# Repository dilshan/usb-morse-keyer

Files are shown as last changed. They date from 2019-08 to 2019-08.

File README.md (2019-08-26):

# USB Morse Keyer
    

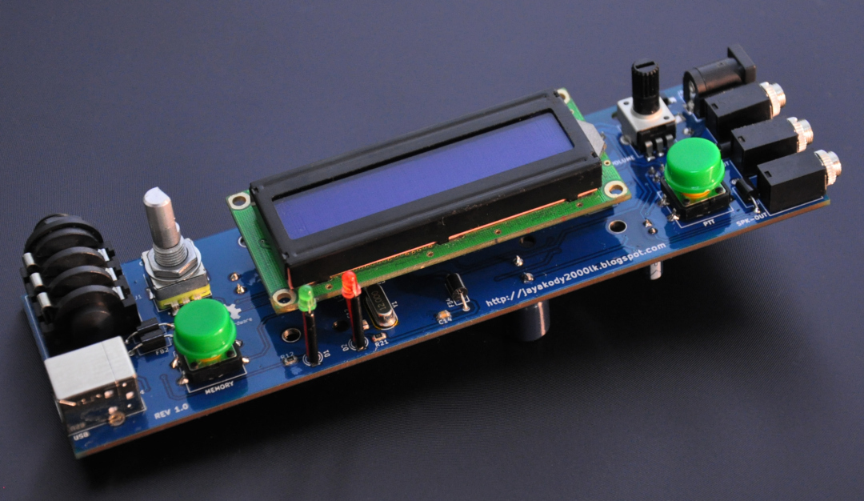
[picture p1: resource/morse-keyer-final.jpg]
Morse Keyer Final Prototype


USB Morse Keyer is microcontroller based keyer with following features:

- USB / straight key / iambic key inputs.
- Support for both *standalone* and *USB* operating modes.
- 64-character USB typeahead buffer and 6-character Morse key typeahead buffer.
- Support 5, 10, 15 WPM.
- 6-page message memory.
- 1W Audio output.
- Audio and PTT output interfaces.
- 32 character display

To reduce the dimension of the PCB this unit is designed with combining both through-hole and surface mount components. To facilitate future upgrades and modifications, the *PIC16F886* MCU sticks with the standard 28-pin DIP package.

The USB interface of this unit is designed to work with most of the operating systems. It emulates a virtual serial terminal to transfer keystrokes to the keyer. In most of the operating systems, this interface works without installing any additional device drivers. To submit keystrokes user can use any serial terminal software such as [PuTTY](https://www.putty.org), *Hyper Terminal*, [Minicom](https://salsa.debian.org/minicom-team/minicom), etc. 

This keyer is designed to work with 7V to 16V DC input voltage. The most recommended working voltage is 9V.

[All the details related to this project are available at project documentation.](https://github.com/dilshan/usb-morse-keyer/wiki)

## Licenses

This is a [certified](https://certification.oshwa.org/lk000004.html) open hardware project and all it's design files, firmware source codes, [documentation](https://github.com/dilshan/usb-morse-keyer/wiki), and other resource files are available at the project source repository. All the content of this project are distributed under the terms of the following license:

- Hardware License: [CC BY 4.0](https://creativecommons.org/licenses/by/4.0/)
- Software License: [MIT](https://github.com/dilshan/usb-morse-keyer/blob/master/LICENSE)
- Documentation License: [CC BY 4.0](https://creativecommons.org/licenses/by/4.0/)

OSHW-LK000004 (https://certification.oshwa.org/lk000004.html)

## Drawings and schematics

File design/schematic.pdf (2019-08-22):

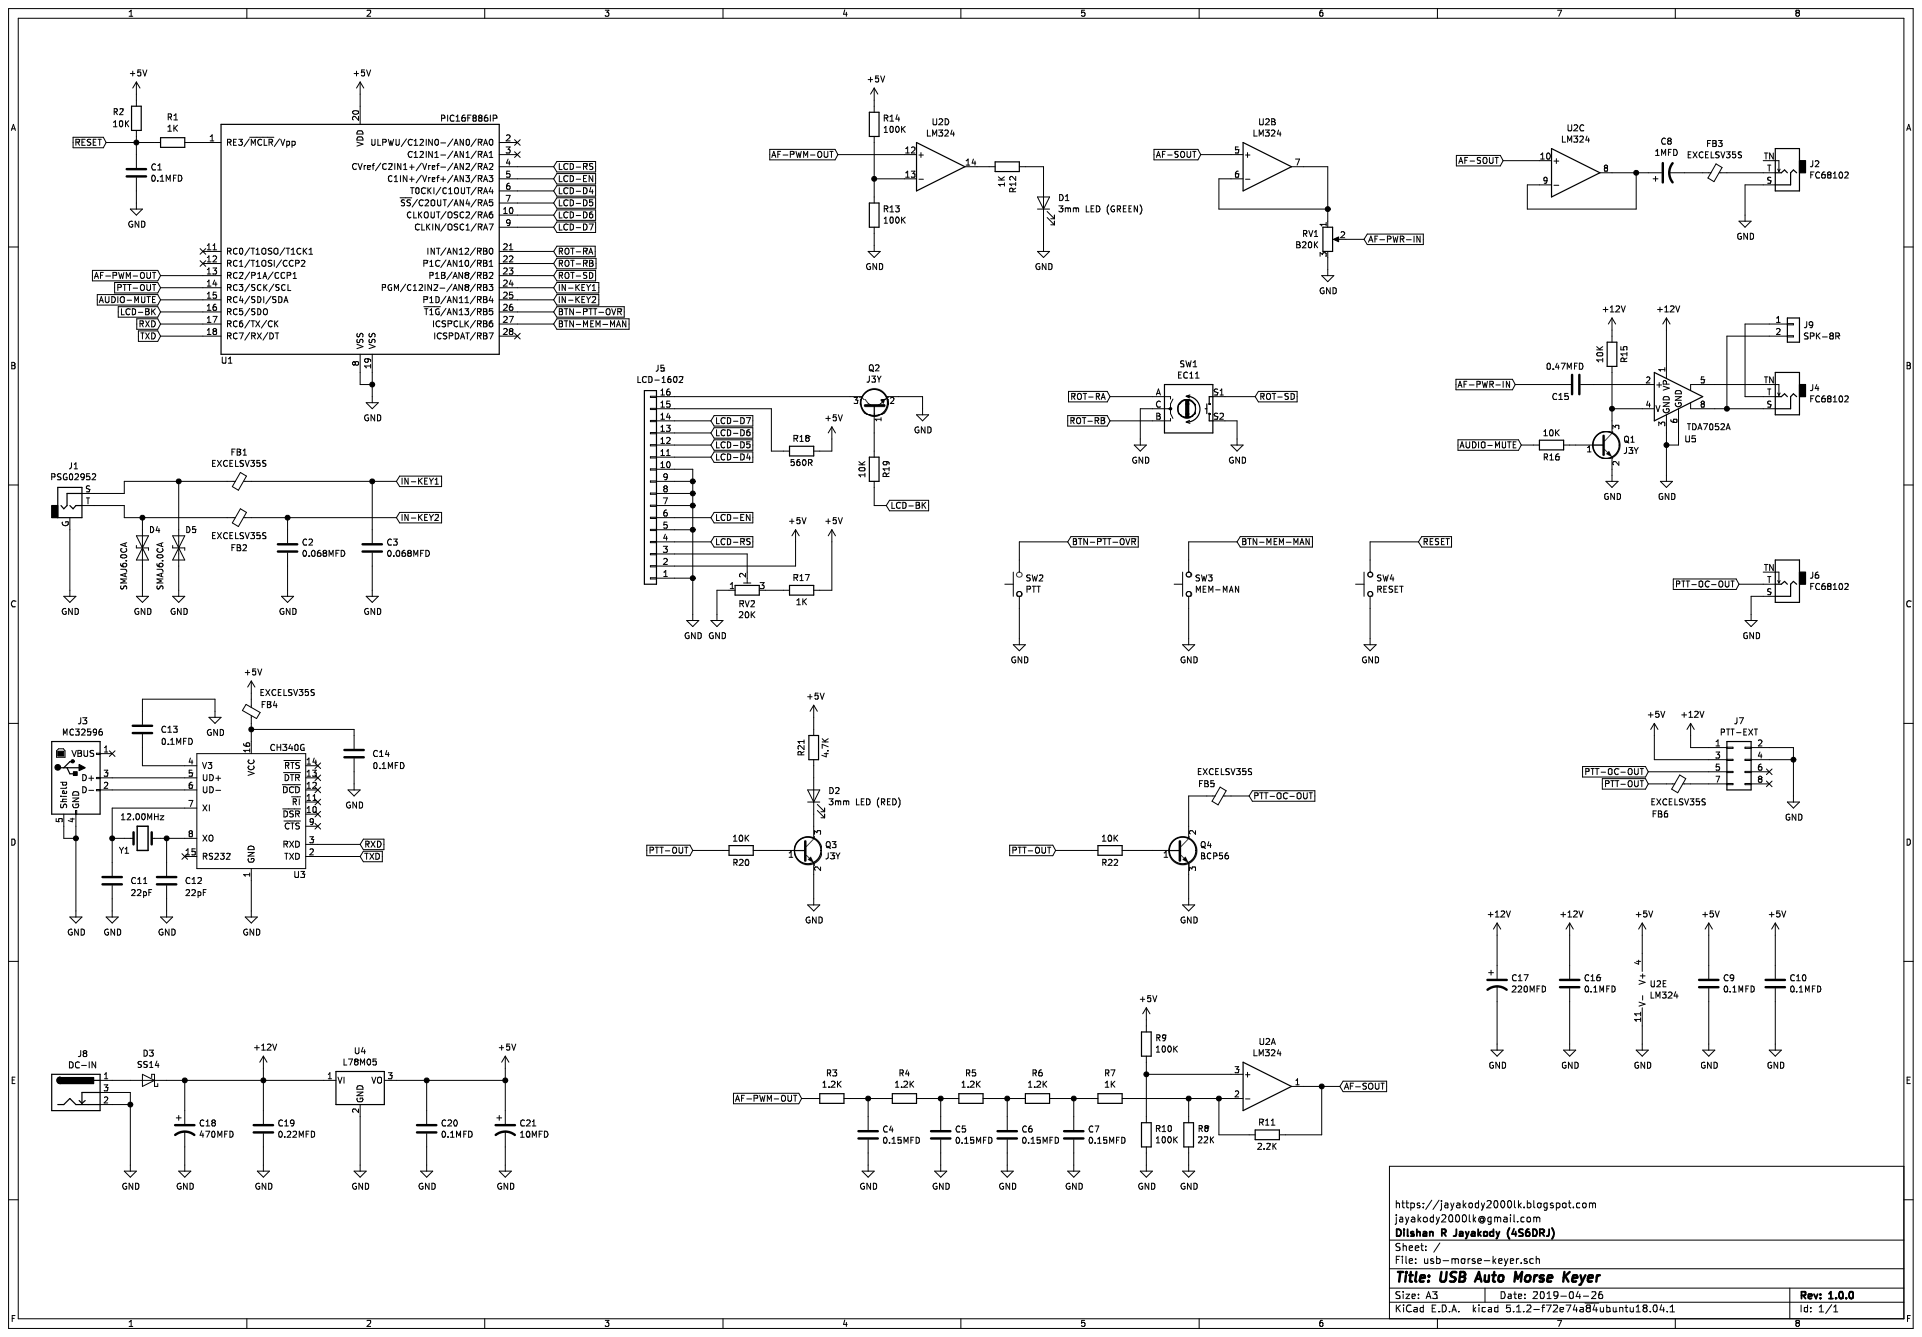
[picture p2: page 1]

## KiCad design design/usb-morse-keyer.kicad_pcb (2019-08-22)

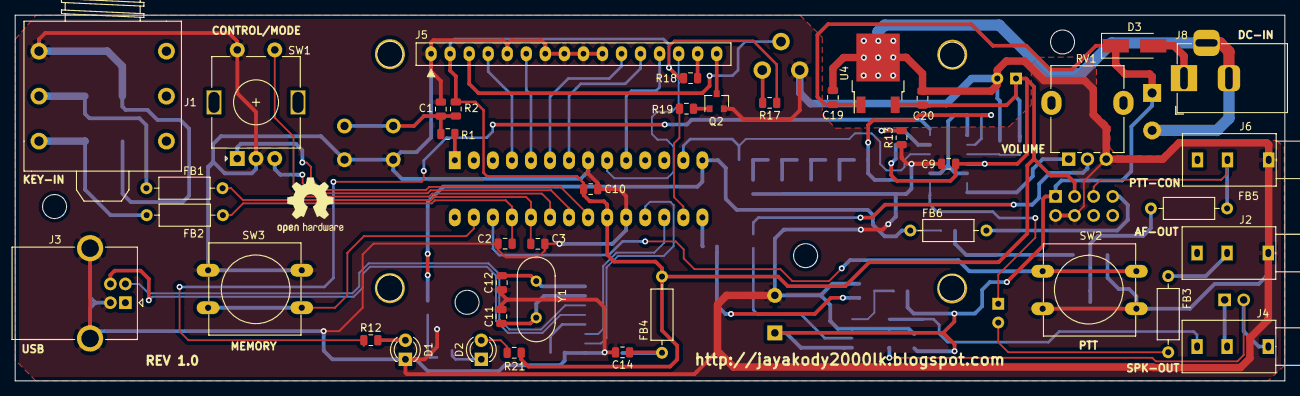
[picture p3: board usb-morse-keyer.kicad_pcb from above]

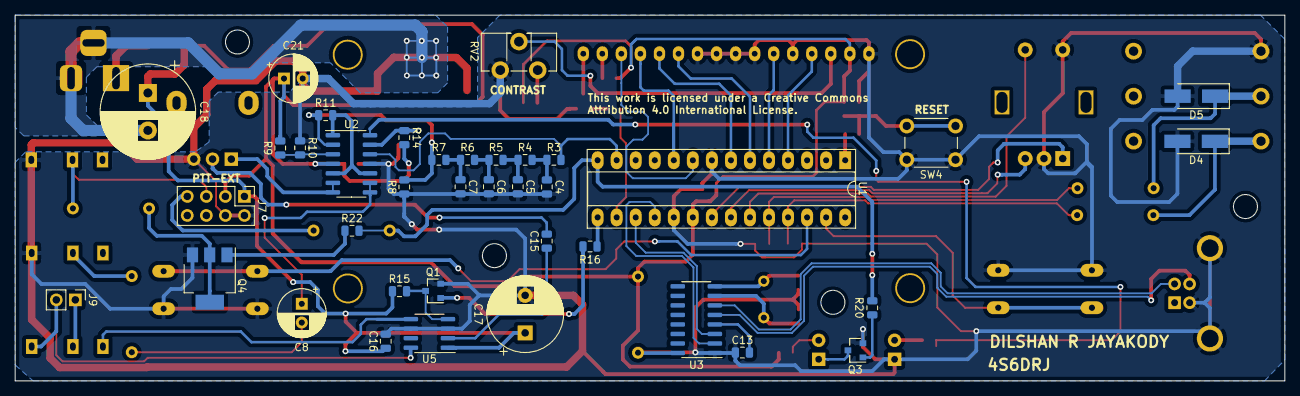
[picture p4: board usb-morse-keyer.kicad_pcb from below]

Board: 2 copper layers, 169.3 x 48.8 mm, 83 parts (38 on the bottom side), 66 nets.

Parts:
 : MountingHole_3.2mm_M3_ISO14580
 #2,  #3,  #4: MountingHole_3.2mm_M3_ISO14580
C1, C9, C10, C13, C14, C16, C20: 0.1MFD; C_0805_2012Metric
C2, C3: 0.068MFD; C_0805_2012Metric
C4, C5, C6, C7: 0.15MFD; C_0805_2012Metric
C8: 1MFD; CP_Radial_D6.3mm_P2.50mm
C11, C12: 22pF; C_0805_2012Metric
C15: 0.47MFD; C_0805_2012Metric
C17: 220MFD; CP_Radial_D10.0mm_P5.00mm
C18: 470MFD; CP_Radial_D12.5mm_P5.00mm
C19: 0.22MFD; C_0805_2012Metric
C21: 10MFD; CP_Radial_D6.3mm_P2.50mm
D1: 3mm LED (GREEN); LED_D3.0mm
D2: 3mm LED (RED); LED_D3.0mm
D3: SS14; D_SMA_Handsoldering
D4, D5: SMAJ6.0CA; D_SMA_Handsoldering
FB1, FB2, FB3, FB4, FB5, FB6: EXCELSV35S; L_Axial_L6.6mm_D2.7mm_P10.16mm_Horizontal_Vishay_IM-2
J1: PSG02952; 6.35mm-Jack-Socket-Stereo
J2, J4, J6: FC68102; 3.5mm-Jack-Socket-Mono
J3: MC32596; USB_B_OST_USB-B1HSxx_Horizontal
J5: LCD-1602; 1602-LCD-Module
J7: PTT-EXT; PinHeader_2x04_P2.54mm_Vertical
J8: DC-IN; BarrelJack_Horizontal
J9: SPK-8R; PinHeader_1x02_P2.54mm_Vertical
Q1, Q2, Q3: J3Y; SOT-23
Q4: BCP56; SOT-223
R1, R7, R12, R17: 1K; R_0805_2012Metric
R2, R15, R16, R19, R20, R22: 10K; R_0805_2012Metric
R3, R4, R5, R6: 1.2K; R_0805_2012Metric
R8: 22K; R_0805_2012Metric
R9, R10, R13, R14: 100K; R_0805_2012Metric
R11: 2.2K; R_0805_2012Metric
R18: 560R; R_0805_2012Metric
R21: 4.7K; R_0805_2012Metric
RV1: B20K; Potentiometer_Alpha_RD901F-40-00D_Single_Vertical
RV2: 20K; Potentiometer_ACP_CA9-H3,8_Horizontal
SW1: EC11; RotaryEncoder_Alps_EC11E-Switch_Vertical_H20mm
SW2: PTT; SW_PUSH-12mm
SW3: MEM-MAN; SW_PUSH-12mm
SW4: RESET; SW_PUSH_6mm
U1: PIC16F886IP; DIP-28_W7.62mm_Socket_LongPads
U2: LM324; SOIC-14_3.9x8.7mm_P1.27mm
U3: CH340G; SOIC-16_3.9x9.9mm_P1.27mm
U4: L78M05; TO-252-2
U5: TDA7052A; SOIC-8_3.9x4.9mm_P1.27mm
Y1: 12.00MHz; Crystal_HC49-U_Vertical

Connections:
+5V: C9.1, C10.1, C20.1, C21.1, FB4.2, J5.2, J7.3, R2.2, R9.2, R14.2, R17.2, R18.2, R21.2, U1.20, U2.4, U4.3
+12V: C16.1, C17.1, C18.1, C19.1, D3.1, J7.1, R15.1, U4.1, U5.1
AF-PWM-OUT: R3.2, U1.13, U2.12
AF-PWR-IN: C15.2, RV1.2
AF-SOUT: R11.2, U2.1, U2.5, U2.10
AUDIO-MUTE: R16.2, U1.15
BTN-MEM-MAN: SW3.2, U1.27
BTN-PTT-OVR: SW2.2, U1.26
GND: C1.2, C2.2, C3.2, C4.2, C5.2, C6.2, C7.2, C9.2, C10.2, C11.2, C12.2, C13.1, C14.2, C16.2, C17.2, C18.2, C19.2, C20.2, C21.2, D1.1, D4.2, D5.2, J1.G, J2.S, J3.4, J3.5, J5.1, J5.5, J5.7, J5.8, J5.9, J5.10, J6.S, J7.2, J7.4, J8.2, J8.3, Q1.2, Q2.2, Q3.2, Q4.3, R8.1, R10.1, R13.1, RV1.3, RV2.1, SW1.C, SW1.S2, SW2.1, SW3.1, SW4.1, U1.8, U1.19, U2.11, U3.1, U4.2, U5.3, U5.6
IN-KEY1: C3.1, FB1.1, U1.24
IN-KEY2: C2.1, FB2.1, U1.25
LCD-BK: R19.2, U1.16
LCD-D4: J5.11, U1.6
LCD-D5: J5.12, U1.7
LCD-D6: J5.13, U1.10
LCD-D7: J5.14, U1.9
LCD-EN: J5.6, U1.5
LCD-RS: J5.4, U1.4
unnamed: C4.1, R3.1, R4.2
unnamed: C5.1, R4.1, R5.2
unnamed: C6.1, R5.1, R6.2
unnamed: C7.1, R6.1, R7.2
unnamed: C8.1, U2.8, U2.9
unnamed: C8.2, FB3.2
unnamed: C11.1, U3.7, Y1.1
unnamed: C12.1, U3.8, Y1.2
unnamed: C13.2, U3.4
unnamed: C14.1, FB4.1, U3.16
unnamed: C15.1, U5.2
unnamed: D1.2, R12.2
unnamed: D2.1, Q3.3
unnamed: D2.2, R21.1
unnamed: D3.2, J8.1
unnamed: D4.1, FB2.2, J1.T
unnamed: D5.1, FB1.2, J1.S
unnamed: FB3.1, J2.T
unnamed: FB5.2, Q4.2, Q4.4
unnamed: FB6.1, J7.7
unnamed: J3.2, U3.6
unnamed: J3.3, U3.5
unnamed: J4.S, J9.2, U5.8
unnamed: J4.T, J9.1
unnamed: J4.TN, U5.5
unnamed: J5.3, RV2.2
unnamed: J5.15, R18.1
unnamed: J5.16, Q2.3
unnamed: Q1.1, R16.1
unnamed: Q1.3, R15.2, U5.4
unnamed: Q2.1, R19.1
unnamed: Q3.1, R20.1
unnamed: Q4.1, R22.1
unnamed: R1.1, U1.1
unnamed: R9.1, R10.2, U2.3
unnamed: R7.1, R8.2, R11.1, U2.2
unnamed: R12.1, U2.14
unnamed: R13.2, R14.1, U2.13
unnamed: R17.1, RV2.3
unnamed: RV1.1, U2.6, U2.7
PTT-OC-OUT: FB5.1, J6.T, J7.5
PTT-OUT: FB6.2, R20.2, R22.2, U1.14
RESET: C1.1, R1.2, R2.1, SW4.2
ROT-RA: SW1.A, U1.21
ROT-RB: SW1.B, U1.22
ROT-SD: SW1.S1, U1.23
RXD: U1.17, U3.3
TXD: U1.18, U3.2

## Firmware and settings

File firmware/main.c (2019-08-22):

/******************************************************************************
 * Copyright (C) 2019 Dilshan R Jayakody.
 * 
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
 * THE SOFTWARE IS PROVIDED "AS IS", WITHOUT WARRANTY OF ANY KIND, EXPRESS OR 
 * IMPLIED, INCLUDING BUT NOT LIMITED TO THE WARRANTIES OF MERCHANTABILITY, 
 * FITNESS FOR A PARTICULAR PURPOSE AND NONINFRINGEMENT. IN NO EVENT SHALL THE 
 * AUTHORS OR COPYRIGHT HOLDERS BE LIABLE FOR ANY CLAIM, DAMAGES OR OTHER 
 * LIABILITY, WHETHER IN AN ACTION OF CONTRACT, TORT OR OTHERWISE, ARISING 
 * FROM, OUT OF OR IN CONNECTION WITH THE SOFTWARE OR THE USE OR OTHER DEALINGS 
 * IN THE SOFTWARE.
 *****************************************************************************/

#include "main.h"
#include "lcd1602.h"
#include "uart.h"
#include "pwm.h"
#include "ringbuffer.h"
#include "morse.h"
#include "mem_manager.h"

int main() 
{
    //Initialize all peripherals, global variables and data structures.
    unsigned char currentChar = 0;
    unsigned char isSleep = 0;
    
    shadowPortC = PORTC;
    systemConfig = loadSystemSettings();
    
    initSystem();
    updateSystemSettings();
    
    initRingBuffer(&dataBuffer);
    initMorseBuffer(&morseCodeBuffer);
            
    __delay_ms(20);
    
    // Activate LCD screen and it's the backlight.
    lastInputStatus = PORTB & PORTB_MASK;
    clearLCD();
    setCursor(1, 1);
    
    __delay_ms(10);
    
    // Enable interrupts to serve user actions.
    enableInterrupts();
    
    // Activate LCD backlight.
    shadowPortC |= 0x20;
    PORTC = shadowPortC;
    
    while(1)
    {
        // Continue main service loop if sleep flag is cleared.
        while(isSleep == 0)
        {
            currentInputStatus = PORTB & PORTB_MASK;

            // Rotary encoder button pressed. Open the system menu.
            if(IS_BUTTON_PRESS(BTN_ROTARY_ENCODER))
            {
                PIE1 = 0x00;
                PIR1 = 0x00;
                sleepCounter = 0;
                
                __delay_ms(50);
                systemMenuHandler();
                saveSystemSettings(systemConfig);
                
                enableInterrupts();
                sleepCounter = 0;

                setCursor(1, 1);
                clearLCD();  
            }

            // Check for PTT override key press.
            if(IS_BUTTON_PRESS(BTN_PTT_OVERRIDE))
            {
                pttOverride = ~pttOverride;
                shadowPortC &= 0xF7;

                if(pttOverride == TRUE)
                {
                    shadowPortC |= 0x08; 
                }

                PORTC = shadowPortC;
                sleepCounter = 0;
                __delay_ms(50);
            }

            // Check for memory keying button press.
            if(IS_BUTTON_PRESS(BTN_MEM_MANAGER))
            {
                __delay_ms(150);
                sleepCounter = 0;
                
                memoryKeyHandler();
                sleepCounter = 0;
                
                setCursor(1, 1);
                clearLCD();
            }

            if(operatingMode == 0x0000)
            {
                // System is in USB mode.
                if(popFromBuffer(&dataBuffer, &currentChar) == 0)
                {
                    printWindow(currentChar);
                    encodeCharacter(currentChar);
                    
                    sleepCounter = 0;
                }
            }
            else 
            {
                // System is in KEY mode.
                generateMorseOutput();

                if(popFromBuffer(&dataBuffer, &currentChar) == 0)
                {
                    printWindow(currentChar);
                    
                    sleepCounter = 0;
                }
            }

            // Check for system idle state.
            if(sleepCounter > SLEEP_TIME_LIMIT)
            {
                sleepCounter = 0;
                
                // Mute AF power amplifier and disable all MCU interrupts.
                PORTC = 0x10;
                INTCON = 0x00;    
                PIE1 = 0x00;
                PIR1 = 0x00;
                
                isSleep = TRUE;
                break;
            }

            lastInputStatus = currentInputStatus;
        }
        
        // Entering sleep mode state...
        __delay_ms(200);
        
        // Sleep mode service routine.
        while(isSleep == TRUE)
        {
            // Wake-up system on PORTB status change.
            if((PORTB & 0x7F) != 0x7F)
            {
                isSleep = 0x00;
                sleepCounter = 0;
            
                shadowPortC |= 0x20;
                PORTC = shadowPortC;
                
                enableInterrupts();
                
                __delay_ms(150);
                currentInputStatus = PORTB & PORTB_MASK;
                lastInputStatus = currentInputStatus;
                
                break;
            }
            __delay_ms(10);
        }
    }
}

void generateMorseOutput()
{
    if(keyerTypeId == 0x00)
    {
        // Handle generic morse keyer.
        if((PORTB & keyerPortMask) == keyerPortMask)
        {
            disablePulse();
        }
        else 
        {
            enablePulse();
        }
    }
    else 
    {
        // Handle paddle type morse keyer and emit output based on active 
        // paddle.
        if((PORTB & keyerPortMask) != keyerPortMask)
        {
            if((PORTB & 0x10) == 0x00)
            {
                // Handle dah (dash) with 3 delay units.
                enablePulse();
                unitDelay();
                unitDelay();
                unitDelay();
                disablePulse();
            }
            else
            {
                // Handle dit (dot) with single delay unit.)
                enablePulse();
                unitDelay();
                disablePulse();
            }
        }
    }
}

void isrTimer0()
{
    // Timer 0 - 250Hz (40ms) interrupt handler (reserved for low priority routines).
    if(T0IF)
    {
        // Check rotary encoder status.
        if((PORTB & 0x03) != 0x03)
        {
            if((!RB0) && (lastEncoderVal))
            {
                if(RB1)
                {
                    encoderPosition++;
                }
                else 
                {
                    encoderPosition = (encoderPosition > 0) ? (encoderPosition - 1) : ROTARY_ENCODER_END;
                }
            }
        }
        
        // Increase sleep counter to detect system idle.
        if(sleepCounter < MAX_SHORT)
        {
            sleepCounter++;
        }
        
        // Restore timer 0 with 250Hz timing cycles.
        lastEncoderVal = RB0; 
        TMR0 = 6;
        T0IF = 0;
    }
}

void isrTimer1()
{
    static unsigned char holdCounter = 0;
    static unsigned char lastMorseCode = 0;
    static unsigned char flagChar = TRUE;
    static unsigned char flagWord = TRUE;
    static unsigned char releaseCounter = MAX_BYTE;
    static unsigned char unitDelayRef = 0;
    
    unsigned char tempDecodeChar;
    
    // Timer 1 - 100Hz (10ms) interrupt handler for time based events.
    if(TMR1IF)
    {
        if(operatingMode == 0x0001)
        {
            // Calculate actual delay for delay unit based on selected WPM.
            switch(keySpeed)
            {
                case 1:
                    unitDelayRef = 12;
                    break;
                case 2:
                    unitDelayRef = 8;
                    break;
                default:
                    unitDelayRef = 24;
            }

            if((PORTB & keyerPortMask) == keyerPortMask)
            {
                // KEY UP state.
                
                // Count key release (idle) time.
                if(releaseCounter < MAX_BYTE)
                {
                    releaseCounter++;
                }

                if((releaseCounter > unitDelayRef) && (lastMorseCode != CODE_EMPTY))
                {
                    // End of morse signal reached.
                    updateMorseBuffer(&morseCodeBuffer, lastMorseCode);
                    lastMorseCode = CODE_EMPTY;
                }

                if((releaseCounter > unitDelayRef * 4) && (flagChar == FALSE))
                {
                    // End of character reached.
                    tempDecodeChar = decodeCharacter(&morseCodeBuffer);
                    if(tempDecodeChar > 0)
                    {
                        pushToBuffer(&dataBuffer, tempDecodeChar);
                    }

                    initMorseBufferISR(&morseCodeBuffer);
                    flagChar = TRUE;
                }

                if((releaseCounter > unitDelayRef * 10) && (flagWord == FALSE))
                {
                    // End of word reached and pushed SPACE into the buffer.
                    pushToBuffer(&dataBuffer, 32);
                    flagWord = TRUE;
                }

                // Detect last key down time and decode morse symbol from that.
                if(holdCounter > 0)
                {
                    if(keyerTypeId == 0x0000)
                    {
                        // Generic morse code key handler to determine keyed symbol.
                        lastMorseCode = (holdCounter >= unitDelayRef * 2) ? CODE_DASH : CODE_DOT;
                    }

                    holdCounter = 0;
                }
            }
            else 
            {
                // KEY DOWN state.   
                if(holdCounter < MAX_BYTE)
                {
                    holdCounter++;
                }

                if(keyerTypeId == 0x0000)
                {
                    // For normal key, wait until user hold the key to determine the symbol.
                    lastMorseCode = CODE_EMPTY;
                }
                else 
                {
                    // Detect which paddle is keyed.
                    lastMorseCode = ((PORTB & 0x10) == 0x00) ? CODE_DASH : CODE_DOT;
                }

                releaseCounter = 0;
                flagChar = FALSE;
                flagWord = FALSE;
            }
        }
        
        // Restore timer 1 with 100Hz timing cycles.
        TMR1H = 177;
        TMR1L = 229;
        TMR1IF = 0;
    }
}

void isrUART()
{
    // UART data receive interrupt.
    unsigned char tempData;
    
    if(RCIF)
    {
        if(operatingMode == 0x0000)
        {
            tempData = readChar();
            // Limit characters to A..Z, a..z, 0..9 and SPACE.
            if(((tempData > 47) && (tempData < 58)) || ((tempData > 64) && (tempData < 91)) || ((tempData > 96) && (tempData < 123)) || (tempData == 32))
            {
                pushToBuffer(&dataBuffer, tempData);
            }
        }
        else 
        {
            // In keying mode ignore data received from the UART.
            RCREG;
        }
    }
}

void __interrupt() systemISR()
{
    // TODO: To handle stack-overflow in some CPUs, convert isrTimer0, isrTimer1 and isrUART to inline.   

    // Timer 0 ISR, reserved for low priority tasks such as monitoring UI ports.
    isrTimer0();
    
    // Timer 1 SIR, reserved for morse keying detection.
    isrTimer1();
    
    // UART ISR, used to capture data received from USB endpoint.
    isrUART();
}

unsigned char systemSubMenuHandler(unsigned char selection, char *menuName, char **menuItems, unsigned char menuItemCount)
{
    signed char lastEncoderPosition = ROTARY_ENCODER_END;
    
    // Display heading of the sub menu.
    clearLCD();
    setCursor(1, 1);
    printStr(menuName);
    
    // Restore last user selection in menu system.
    encoderPosition = selection;
    lastInputStatus = PORTB & PORTB_MASK;
    
    while(1)
    {
        currentInputStatus = PORTB & PORTB_MASK;
        
        if(lastEncoderPosition != encoderPosition)
        {
            clearRow(2);
            lastEncoderPosition = encoderPosition;
            
            // Handle end of rotary encoder limit.
            if(encoderPosition == ROTARY_ENCODER_END)
            {
                encoderPosition = menuItemCount - 1;
            }
            
            // Handle last element of the selection list.
            if(encoderPosition == menuItemCount)
            {
                encoderPosition = 0;
            }
            
            printStr(menuItems[encoderPosition]);
        }
        
        // Check for user confirmation action.
        if(IS_BUTTON_PRESS(BTN_ROTARY_ENCODER))
        {
            return encoderPosition;
        }
        
        lastInputStatus = currentInputStatus;
    }
}

void updateSystemSettings()
{
    // Update global variables based on settings value.
    operatingMode = systemConfig & 0x0003;
    keyerTypeId = systemConfig & 0x000C;
    keySpeed = (systemConfig >> OPT_SPEED) & 0x03;
    keyerPortMask = ((keyerTypeId == 0x0000) ? 0x08: 0x18);
    toneType = (systemConfig >> OPT_TONE_TYPE) & 0x03;
    loopMessage = (systemConfig >> OPT_LOOP_SEND) & 0x03;
    
    // Update audio amplifier mute state.    
    shadowPortC &= 0xEF;
    
    if((systemConfig & 0x00C0) != 0x0000)
    {
        shadowPortC |= 0x10;
    }
    
    PORTC = shadowPortC;
}

void memoryKeyHandler()
{
    signed char lastEncoderPosition = ROTARY_ENCODER_END;
    unsigned char memAddr = MEM_MSG_BASE;
    unsigned char memData = 0;
    unsigned char memPos = 0;
    unsigned char buttonHoldCounter = 0;
    unsigned char currentChar;
    unsigned char charCount = MEM_MSG_SIZE;
    unsigned char waitTimeCount = 0;
    unsigned char userCancel = 0;

    // Initiate a memory manager.
    clearLCD();
    setCursor(1, 1);
    printStr("Memory slot");
    
    encoderPosition = 0;
    lastInputStatus = PORTB & PORTB_MASK;
    
    while(1)
    {
        currentInputStatus = PORTB & PORTB_MASK;
        
        // Check for PTT override key press.
        if(IS_BUTTON_PRESS(BTN_PTT_OVERRIDE))
        {
            pttOverride = ~pttOverride;
            shadowPortC &= 0xF7;
            
            if(pttOverride == TRUE)
            {
                shadowPortC |= 0x08; 
            }
            
            PORTC = shadowPortC;
            __delay_ms(50);
        }
        
        // Rotary encoder button is pressed to play the selected slot.
        if(IS_BUTTON_PRESS(BTN_ROTARY_ENCODER))
        {
            __delay_ms(50);
            
            // Play routine is built into this function to save stack levels.
            
            // Get a first byte from the selected memory page.
            memAddr = MEM_MSG_BASE + (encoderPosition * (MEM_MSG_SIZE + 1));
            currentChar = eeprom_read(memAddr);
            
            // Check for empty slot.
            if(currentChar != END_OF_MESSAGE)
            {
                clearRow(2);
                clearScrollBuffer();
                
                charCount = 0;
                lastInputStatus = PORTB & PORTB_MASK;
                userCancel = 0;
                
                // Message looping cycle. This loop iterates only if LOOPING 
                // is enabled in system settings. 
                while(userCancel == 0)
                {
                    while(charCount < MEM_MSG_SIZE + 1)
                    {
                        currentInputStatus = PORTB & PORTB_MASK;

                        // Wait for stop action (cancel) from user.
                        if((currentInputStatus & BTN_MEM_MANAGER) == 0x00)
                        {
                            clearRow(2);
                            printStr("CANCEL");

                            while((PORTB & BTN_MEM_MANAGER) == 0x00)
                            {
                                __delay_ms(10);
                            }

                            currentInputStatus = PORTB & PORTB_MASK;
                            lastInputStatus = currentInputStatus;
                            userCancel = TRUE;
                            
                            __delay_ms(150);
                            break;
                        }

                        // Check for end of message mark to stop the playback.
                        if(currentChar == END_OF_MESSAGE)
                        {
                           break; 
                        }

                        // Print current character and release morse code.
                        printScroll(currentChar);
                        encodeCharacter(currentChar);

                        // Reading next character from the memory slot.
                        currentChar = eeprom_read(++memAddr);

                        lastInputStatus = currentInputStatus;
                    }
                    
                    // End of message transmission and now check looping flag.
                    if(loopMessage == 0x00)
                    {
                        // Read first character of the message from the memory slot.
                        memAddr = MEM_MSG_BASE + (encoderPosition * (MEM_MSG_SIZE + 1));
                        currentChar = eeprom_read(memAddr);
                        
                        clearRow(2);
                        printStr("LOOPING  ");
                
                        charCount = 0;
                        waitTimeCount = 0;
                        
                        // Break looping if user issues cancel. 
                        if(userCancel == TRUE)
                        {
                            break;
                        }
          
                        // Lets keep 21 units of spacing between each message. 
                        while(waitTimeCount < 21)
                        {
                            waitTimeCount++;
                            currentInputStatus = PORTB & PORTB_MASK;
                            
                            // Update looping progress indicator.
                            if((waitTimeCount % 3) == 0)
                            {
                                printChar(0xFF);
                            }
                            
                            unitDelay();
                            
                            // Check for cancel action from user.
                            if((currentInputStatus & BTN_MEM_MANAGER) == 0x00)
                            {
                                clearRow(2);
                                printStr("CANCEL");

                                while((PORTB & BTN_MEM_MANAGER) == 0x00)
                                {
                                    __delay_ms(10);
                                }

                                currentInputStatus = PORTB & PORTB_MASK;
                                lastInputStatus = currentInputStatus;
                                userCancel = TRUE;
                                
                                __delay_ms(150);
                                break;
                            }
                            
                        }
                        
                        clearRow(2);
                        clearScrollBuffer();
                        lastInputStatus = PORTB & PORTB_MASK;
                    }
                    else 
                    {
                        // Looping is not active.
                        break;
                    }
                    
                    // Handle cancel state issued by the user.
                    if(userCancel == TRUE)
                    {
                        __delay_ms(10);
                        break;
                    }
                }
                
                clearLCD();
                setCursor(1, 1);
                printStr("Memory slot");
                lastEncoderPosition = ROTARY_ENCODER_END;
            }
        }
        
        // Toggle MEM button to close the memory manager.
        if(IS_BUTTON_PRESS(BTN_MEM_MANAGER))
        {
            __delay_ms(50);
            break;
        }
        
        // Watch button hold down counter to initiate the recording session.
        if((currentInputStatus & BTN_MEM_MANAGER) == 0x00)
        {
            buttonHoldCounter++;
            
            if(buttonHoldCounter >= 60)
            {
                buttonHoldCounter = 0;
                memAddr = 0;
                charCount = MEM_MSG_SIZE;
                
                // Start recording session. In here recording routine is in the 
                // same function to save the stack.
                clearLCD();
                setCursor(1, 1);
                printStr("Recording...");

                clearScrollBuffer();
                
                while((PORTB & BTN_MEM_MANAGER) == 0x00)
                {
                    __delay_ms(10);
                }

                __delay_ms(20);
                lastInputStatus = PORTB & PORTB_MASK;
                
                while(1)
                {
                    currentInputStatus = PORTB & PORTB_MASK;

                    // Wait for stop action (cancel) from user.
                    if(IS_BUTTON_PRESS(BTN_MEM_MANAGER))
                    {
                        __delay_ms(150);
                        break;
                    }

                    // Rotary encoder button event to save captured message to the memory.
                    if(IS_BUTTON_PRESS(BTN_ROTARY_ENCODER))
                    {
                        eepromBuffer[memAddr] = END_OF_MESSAGE;
                        saveMsgBuffer(eepromBuffer, encoderPosition);

                        __delay_ms(10);
                        break;
                    }
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

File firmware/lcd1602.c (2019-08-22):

/******************************************************************************
 * Copyright (C) 2019 Dilshan R Jayakody.
 * 
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
 * THE SOFTWARE IS PROVIDED "AS IS", WITHOUT WARRANTY OF ANY KIND, EXPRESS OR 
 * IMPLIED, INCLUDING BUT NOT LIMITED TO THE WARRANTIES OF MERCHANTABILITY, 
 * FITNESS FOR A PARTICULAR PURPOSE AND NONINFRINGEMENT. IN NO EVENT SHALL THE 
 * AUTHORS OR COPYRIGHT HOLDERS BE LIABLE FOR ANY CLAIM, DAMAGES OR OTHER 
 * LIABILITY, WHETHER IN AN ACTION OF CONTRACT, TORT OR OTHERWISE, ARISING 
 * FROM, OUT OF OR IN CONNECTION WITH THE SOFTWARE OR THE USE OR OTHER DEALINGS 
 * IN THE SOFTWARE.
 *****************************************************************************/

#include "lcd1602.h"

void sendCommand(unsigned char cmd)
{
    PORTA &= 0x03;
    __delay_us(50);
    PORTA |= cmd << 4;
    PORTA |= 0x08;
    __delay_ms(4);
    PORTA &= 0xF7;
}

void initLCD()
{
    PORTA = 0x00;
    __delay_ms(5);
    
    // Try to reset the HD44780 controller.
    sendCommand(0x03);
    __delay_ms(5);
    sendCommand(0x03);
    __delay_ms(15);
    sendCommand(0x03);
    
    // Initialize display with default character set font size.
    sendCommand(0x02);
    sendCommand(0x02);
    sendCommand(0x08);
    sendCommand(0x00);
    sendCommand(0x0C);
    sendCommand(0x00);
    sendCommand(0x06);
}

void clearLCD()
{
    sendCommand(0x00);
    sendCommand(0x01);
    
    displayRow = 1;
    displayCol = 1;
}

void printChar(char value)
{
    char lowWord = (value & 0x0F) << 4;
    
    // Send high value of the byte.
    PORTA |= 0x04;
    PORTA = (PORTA & 0x0F) | (value & 0xF0);
    PORTA |= 0x08;
    
    // Send low value of the byte.
    __delay_us(50);
    PORTA &= 0xF7;
    PORTA = (PORTA & 0x0F) | lowWord;
    PORTA |= 0x08;
    
    __delay_us(50);
    PORTA &= 0xF7;
}

void printStr(char *str) 
{
    unsigned char pos;
    for(pos = 0; str[pos]!='\0'; pos++)
    {
        printChar(str[pos]);
    }
}

void printWindow(char value)
{
    if((++displayCol) > MAX_DISPLAY_LENGTH)
    {
        // End of column reached and switch to the next row of the display.
        displayCol = 1;
        if((++displayRow) == 3)
        {
            // All display rows are filled, lets clear the display.
            displayRow = 1;
            clearLCD();
        }
        
        setCursor(displayRow, displayCol);
    }
    
    printChar(value);
}

void setCursor(unsigned char row, unsigned char col)
{
    unsigned char cmd = (row == 1 ? 0x80 : 0xC0) + col - 1;
    sendCommand(cmd >> 4);
    sendCommand(cmd & 0x0F);
    
    displayRow = row;
    displayCol = col;
}

void clearRow(unsigned char row) 
{
    unsigned char pos;
    setCursor(row, 1);
    for(pos = 0; pos < 16; pos++)
    {
        printChar(' ');
    }
    setCursor(row, 1);
}

void clearScrollBuffer()
{
    unsigned char scrollBufferPos;
    
    scrollPos = 0;
    
    for(scrollBufferPos = 0; scrollBufferPos < MAX_DISPLAY_LENGTH; scrollBufferPos++)
    {
        scrollBuffer[scrollBufferPos] = 32;
    }
    
    scrollBuffer[MAX_DISPLAY_LENGTH] = 0;
}

void printScroll(char value)
{
    unsigned char scrollBufferPos;
    
    setCursor(2,1);
    
    if(scrollPos >= MAX_DISPLAY_LENGTH)
    {
        // Scroll buffer is full. Shift each character of the display to left side.
        for(scrollBufferPos = 1; scrollBufferPos < MAX_DISPLAY_LENGTH; scrollBufferPos++)
        {
            scrollBuffer[scrollBufferPos - 1] = scrollBuffer[scrollBufferPos];
        }
        
        // Append current character into the tail of the scroll buffer.
        scrollBuffer[scrollBufferPos - 1] = value;
    }
    else 
    {
        // Scroll buffer has enough space for character(s).
        scrollBuffer[scrollPos] = value;
        scrollPos++;
    }
    
    // Update display with scroll buffer content.
    printStr(scrollBuffer);
}

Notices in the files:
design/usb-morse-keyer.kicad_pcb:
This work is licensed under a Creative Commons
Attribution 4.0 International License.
